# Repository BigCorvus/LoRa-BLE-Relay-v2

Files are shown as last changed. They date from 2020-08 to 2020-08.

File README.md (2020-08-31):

# LoRa-BLE-Relay-v2
second version of the nRF52840 and SX126x-based communication device intended to run Meshtastic-
This version is in the testing process. Not confirmed working yet.

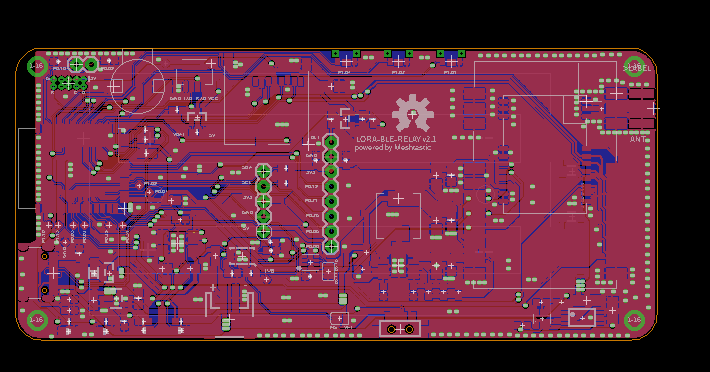
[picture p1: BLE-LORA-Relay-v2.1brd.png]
LoraRelayV2
  
See fourm discussion https://meshtastic.discourse.group/t/building-for-nrf52-boards/457/62  

The initial 2.0 version:  
LoraRelayV2  
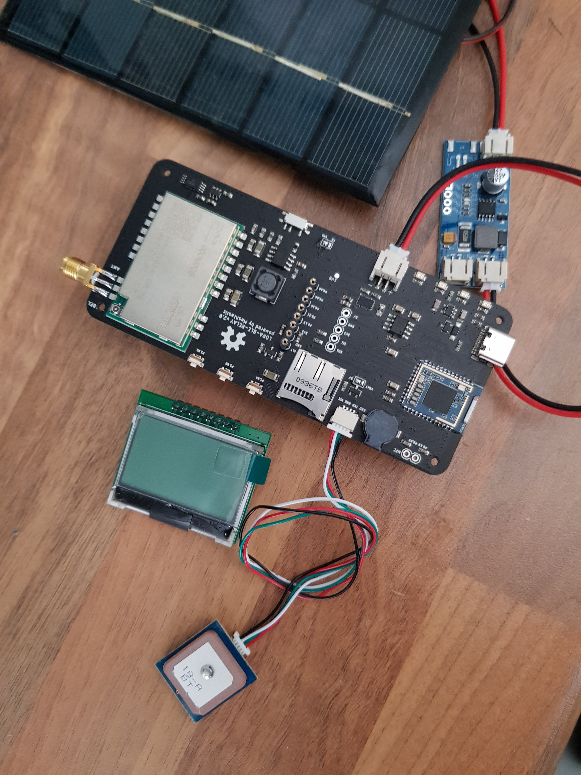
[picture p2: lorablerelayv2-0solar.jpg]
LoraRelayV2s
  

Features are: 
- 110x50mm  
- more ground plane for better LoRa RF performance
- low power consumption in receive mode and Bluetooth active: about 20mA for the 30dbm and 10mA for the 22dbm module version  
- nRF52840 module by Waveshare/HolyIOT with native USB bootloader, broken out NFC pins and good Arduino support (Adafruit Core)  
- Ebyte E22 LoRa Modules based on new Semtech SX126x chipsets for 22 or 30dbm and 915,868,433...Mhz frequency bands. 
- Footprint for both the big and the small LoRa module (the boost converter doesn't need to be assembled if the smaller one is used)  
- SD card slot (same card holder as in the Adafruit Adalogger boards  
- On board buzzer  
- GPS connector breaking out RXD and TXD (JST-SH 4-pin) with high-side power cutting option.   
- Many screen options: usual 128x64 OLEDs via I2C or sunlight-readable and power-efficient ST7565R and UC1701X LCD screens via bitbanged 4 line SPI (see BOM for variants)  
- display headers can be expansion headers  
- 3 nav buttons  
- powered from 1 or 2 parallel unprotected 18650 cells (protection circuitry on board)  
- port for external battery or solar charger for concurrent charging  
- battery temperature monitoring/environmental sensing via BME280  
- USB-C connector
- power management via TI fuel gauge IC with optional programmable power cutting option  (selectable via solder jumper, experimental!) 

To do in next version: reverse polarity protection for batteries.

Installation of the Arduino variant: put the variant.h and .cpp in a folder named LoRaBLERelayV2 which has to be created inside the variants folder of the nrf52 core. There you also have boards.txt which you have to extend by the content of the boards.txt inside this repo.

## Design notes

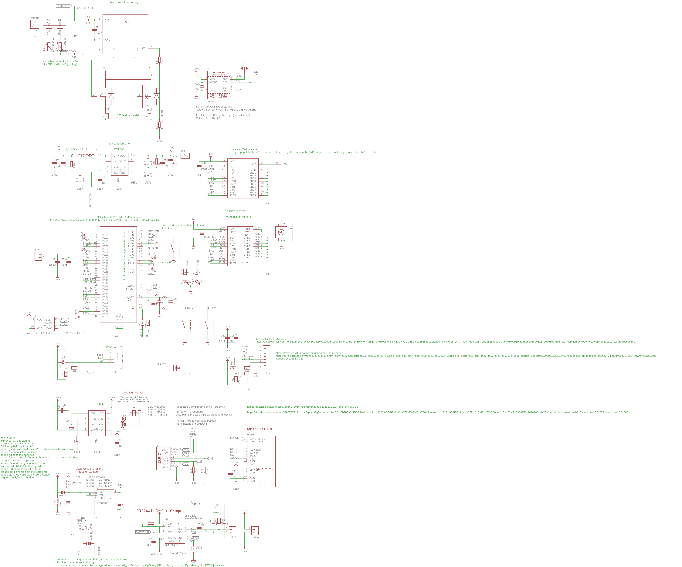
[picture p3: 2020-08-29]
BLE-LORA-Relay-v2.1.png

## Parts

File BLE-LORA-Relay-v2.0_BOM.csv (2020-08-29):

Qty | Value | Device | Package | Parts | Description | Search Keywords, remarks | Buying URL
3 |  | M02PTH | 1X02 | JP2, JP4, JP7 | Standard 2-pin 0.1 header. Use with"
1 |  | M08 | 1X08_ROUND | JP1 | Header 8
1 |  | PINHD-1X1 | 1X01 | JP3 | Pin header 1x1 for 0.1 spacing"
1 |  | SMACONNECTOR_EDGE | SMA_EDGELAUNCH | ANT | SMA Connector
1 |  | USB_C16PIN | USB-C-16P | J2 | USB Type C 16Pin Connector | USB Type c 16 pin | https://de.aliexpress.com/item/33056042016.html?spm=a2g0s.9042311.0.0.4a9b4c4dQIyuQ2
1 | 0.47uF | CAP0603-CAP | 0603-CAP | C4 | Capacitor
3 | 1.0uF | 1.0UF-16V-10%(0603) | 0603-CAP | C5, C12, C17 | CAP-00868
1 | 1.1k | R-EU_R0603 | R0603 | R4 | RESISTOR, European symbol
1 | 100R | R-EU_R0603 | R0603 | R23 | RESISTOR, European symbol
5 | 100k | R-EU_R0603 | R0603 | R25, R1, R2, R24, R28 | RESISTOR, European symbol
3 | 100n | 1.0UF-16V-10%(0603) | 0603-CAP | C11, C22, C3 | CAP-00868
4 | 100µ | C-EUC1206 | C1206 | C2, C16, C20, C21 | CAPACITOR, European symbol
2 | 10k | RESISTOR_0603_NOOUT | 0603-NO | R10, R11 | Resistors
1 | 10mOhm | R-EU_R0805 | R0805 | R5 | RESISTOR, European symbol
9 | 10...47uF | CAP_CERAMIC0805-NOOUTLINE | 0805-NO | C13, C15, C6, C7, C8, C10, C1, C9, C23 | Ceramic Capacitors
1 | 12k | R-EU_R0603 | R0603 | R20 | RESISTOR, European symbol
2 | 130pf | 1.0UF-16V-10%(0603) | 0603-CAP | C14, C19 | CAP-00868
7 | 1K | RESISTOR_0603_NOOUT | 0603-NO | R3, R7, R16, R17, R8, R26, R27 | Resistors
1 | 22R | RESISTOR_0603_NOOUT | 0603-NO | R22 | Resistors
1 | 27p | C-EUC0603 | C0603 | C18 | CAPACITOR, European symbol
1 | 2X18650 | 2X18650 | 2X18650 | U$10 |  | single or dual 18650 holder, surface mount | https://de.aliexpress.com/item/4000868337607.html?s=p&ad_pvid=20200719050327118341633435090009798010_2
1 | 3.3k | R-EU_R0603 | R0603 | R19 | RESISTOR, European symbol
1 | 4.7R | R-EU_R0603 | R0603 | R18 | RESISTOR, European symbol
4 | 5.1k | R-EU_R0603 | R0603 | R12, R13, R6, R9 | RESISTOR, European symbol
2 | 68R | RESISTOR_0603_NOOUT | 0603-NO | R14, R15 | Resistors
1 | 7.5MM-COIL | 7.5MM-COIL | 7.5MM_COIL | U$35
1 | 8205A | 8205A | TSSOP8 | U$46 | Dual Mosfet
1 | 82k | R-EU_R0603 | R0603 | R21 | RESISTOR, European symbol
1 | AP2112(3.3V) | VREG_SOT23-5 | SOT23-5 | U2 | SOT23-5 Fixed Voltage Regulators
1 | BLUE | LED0805_NOOUTLINE | CHIPLED_0805_NOOUTLINE | D4 | LED
1 | BME280 | BME280 | BME280 | U3 | BME280 - Environmental Sensor (I2C + SPI)
1 | BQ27441-G1 | BQ27441-G1 | PDSO-N12 | U1 | Fuel gauge IC
1 | BUZZER | BUZZER | BUZZER | U$2 |  | 9032 9,0 x 3.2 magnetic buzzer | https://de.aliexpress.com/item/4000148853278.html
3 | DMG2305 | MOSFET-P | SOT23-R | Q2, Q3, Q4 | P-Channel Mosfet
1 | DW-01 | DW-01 | SOT23-6 | U$38 | Lithium protection IC
1 | G5177C | G5177C | SO-08 | U$41 | Synchronous boost converter IC
1 | JST-SH-3 | JST-SH-3 | JST-SH-3 | U$17 | actually, surface mount 4-pin 1mm connector for GPS: JST-SH4
1 | JSTPH | CON_JST_PH_2PIN | JSTPH2 | X1 | JST 2-Pin Right-Angle Connector
3 | LS12T2 | LS12T2 | LS12T2 | DWN, DWN1, DWN2 | Pushbutton | Digikey 1642-1312-1-ND
1 | MBR120 | DIODE-SCHOTTKYSOD-123 | SOD-123 | D1
1 | NRF52840 | NRF52840 | NRF52840MOD | U$14 | Manufactued by HolyIOT or waveshare |  | https://de.aliexpress.com/item/32868002366.html?spm=a2g0s.9042311.0.0.27424c4duvmlGy
3 | RED | LED0805_NOOUTLINE | CHIPLED_0805_NOOUTLINE | D2, D3, D5 | LED
1 | SWITCH_SPDT | SWITCH_SPDT | KPS-1290 | U$45 | SWCH-10651 | SPDT MSK-12C02 | https://de.aliexpress.com/item/32856542440.html
1 | SX1262-30DBM | SX1262-30DBM | SX1262-30DBM | U$15 | 1W LoRa module by ebyte | search ebyte on aliexpress and get the E22 variants which can contain either a SX1262 or SX1268 and come in 22dbm or 30dbm variants
1 | SX1292-EBYTE | SX1292-EBYTE | SX1262_EBYTE | U$36 | 22dbm LoRa module by ebyte
1 | TP4056 | TP4056 | SO-08 | U$3 | Lithium charger
6 | TPSQTP13R | TPSQTP13R | TP13R | 1V8, 3V3, G, RST, SWC, SWD | Test pad
1 | microsd | MICROSD | MICROSD | X4 | MicroSD/Transflash Card Holder with SPI pinout |  | https://de.aliexpress.com/item/32607879172.html
1 | 1.4 inch ST7565 LCD 128x64 |  |  |  |  | preferred variant | https://de.aliexpress.com/item/32849604267.html
 | Alternative: UC1701X-based, bigger screen, same pinout, model: JLX12864G-086-P |  |  |  |  |  | https://de.aliexpress.com/item/32828243113.html
2 |  | Ferrite Bead 3A | 1206 | R29, 30 |  | 553-2402-1-ND Digikey

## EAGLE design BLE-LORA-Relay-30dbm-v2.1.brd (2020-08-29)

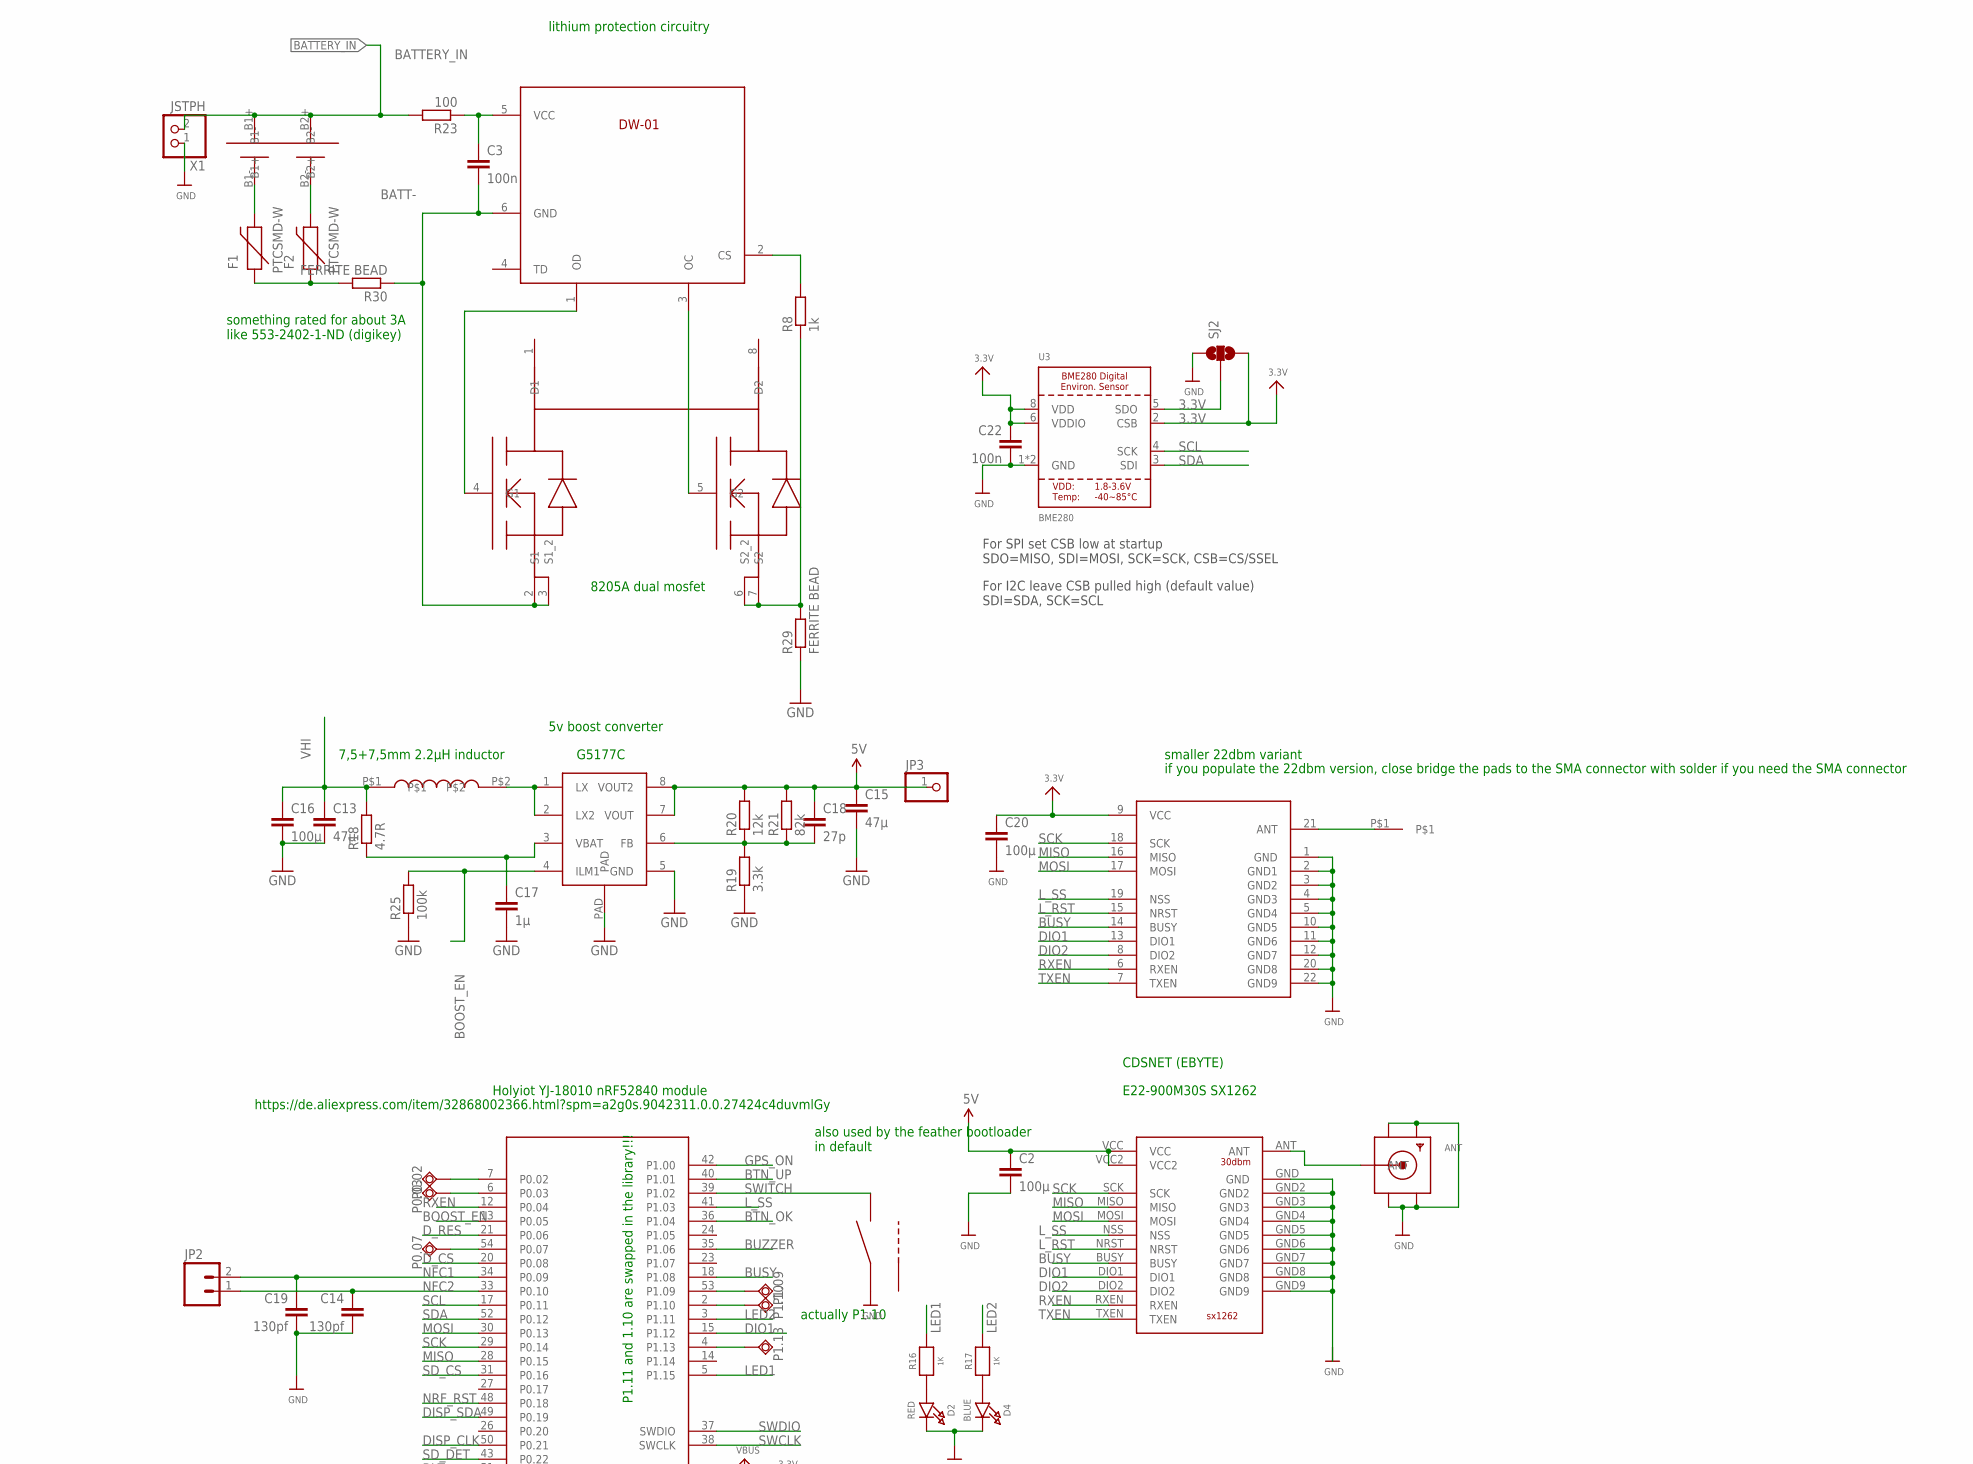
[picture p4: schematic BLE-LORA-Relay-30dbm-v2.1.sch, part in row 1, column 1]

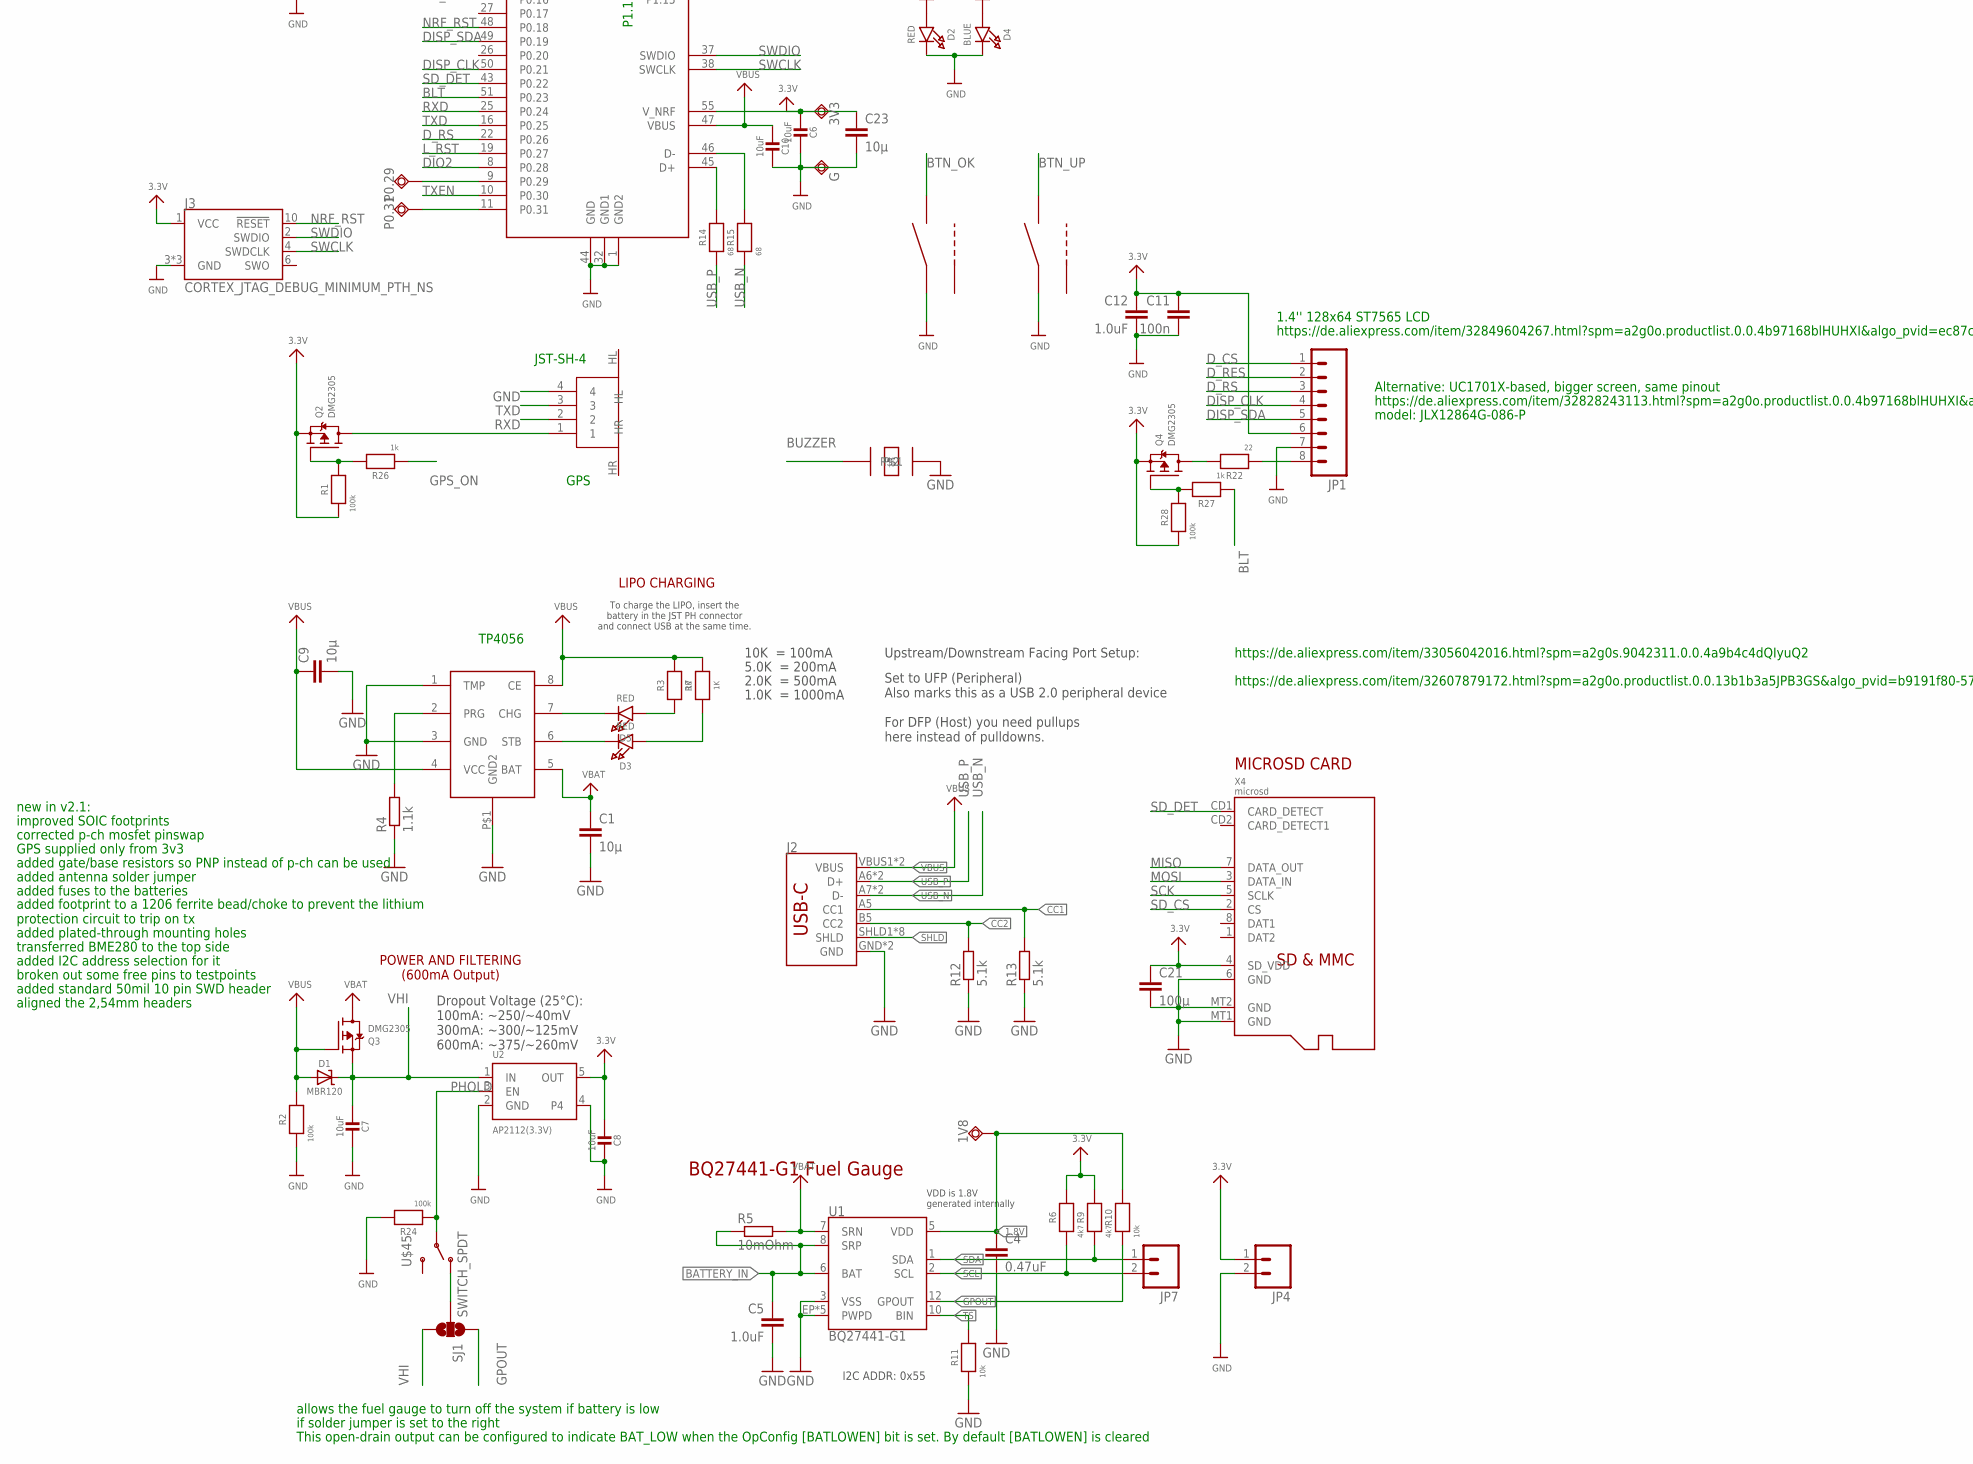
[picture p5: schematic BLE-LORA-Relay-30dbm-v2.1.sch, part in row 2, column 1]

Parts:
1V8, 3V3: TPSQTP13R; TP13R
ANT: SMACONNECTOR_EDGE; SMA_EDGELAUNCH
C1, C9, C23: 10µ; C0805
C2, C16, C20, C21: 100µ; C1206
C3: 100n; C0603
C4: 0.47uF; 0603-CAP
C5, C12: 1.0uF; 0603-CAP
C6, C7, C8, C10: 10uF; 0805-NO
C11, C22: 100n; 0603-CAP
C13, C15: 47µ; C0805
C14, C19: 130pf; 0603-CAP
C17: 1µ; C0603
C18: 27p; C0603
D1: MBR120; SOD-123
D2, D3, D5: RED; CHIPLED_0805_NOOUTLINE
D4: BLUE; CHIPLED_0805_NOOUTLINE
DWN, DWN1, DWN2: LS12T2
F1, F2: PTCSMD-W; PTC-1206-WIDE
G: TPSQTP13R; TP13R
J2: USB_C16PIN; USB-C-16P
J3: CORTEX_JTAG_DEBUG_MINIMUM_PTH_NS; 2X5-PTH-1.27MM-NO_SILK
JP1: M08; 1X08_ROUND
JP2, JP4, JP7: M02PTH; 1X02
JP3: PINHD-1X1; 1X01
P0.02, P0.03, P0.07, P0.29, P0.31, P1.09, P1.10, P1.13: TPSQTP13R; TP13R
Q2, Q3, Q4: DMG2305; SOT23-R
R1, R2, R24, R28: 100k; 0603-NO
R3, R7, R16, R17: 1K; 0603-NO
R4: 1.1k; R0603
R5: 10mOhm; R0805
R6, R9: 4k7; 0603-NO
R8: 1k; R0603
R10, R11: 10k; 0603-NO
R12, R13: 5.1k; R0603
R14, R15: 68; 0603-NO
R18: 4.7R; R0603
R19: 3.3k; R0603
R20: 12k; R0603
R21: 82k; R0603
R22: 22; 0603-NO
R23: 100; R0603
R25: 100k; R0603
R26, R27: 1k; 0603-NO
R29, R30: FERRITE BEAD; R1206
SJ1, SJ2: SOLDERJUMPER_2WAY-OLDS; SJ_3
U1: BQ27441-G1; PDSO-N12
U2: AP2112(3.3V); SOT23-5
U3: BME280
U$2: BUZZER
U$10: 2X18650
U$14: NRF52840; NRF52840MOD
U$15: SX1262-30DBM
U$17: JST-SH-3
U$35: 7.5MM-COIL; 7.5MM_COIL
U$36: SX1292-EBYTE; SX1262_EBYTE
U$38: DW-01; SOT23-6
U$39: G5177C_G5177C; G5177C_SO-08
U$41: SOLDERPAD
U$45: SWITCH_SPDT; KPS-1290
U$46: 8205A; TSSOP8
U$47: TP4056BETTER_TP4056; TP4056BETTER_SO-08
X1: JSTPH; JSTPH2
X4: microsd; MICROSD

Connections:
1.8V: 1V8.TP, C4.1, R10.2, U1.5 (VDD)
3.3V: 3V3.TP, C6.2, C8.2, C11.1, C12.1, C20.1, C21.1, C22.1, C23.1, J3.1 (VCC), JP1.6, JP4.1, Q2.2 (S), Q4.2 (S), R1.1, R6.2, R9.2, R28.1, SJ2.3, U2.5 (OUT), U3.2 (CSB), U3.6 (VDDIO), U3.8 (VDD), U$14.55 (V_NRF), U$36.9 (VCC), X4.4 (SD_VDD)
5V: C2.1, C15.1, C18.1, JP3.1, R20.2, R21.2, U$15.VCC, U$15.VCC2, U$39.7 (VOUT), U$39.8 (VOUT2)
ANT: ANT.P (ANT), U$15.ANT
BATT-: C3.2, R30.1, U$38.6 (GND), U$46.2 (S1), U$46.3 (S1_2)
BATTERY_IN: C5.1, R5.1, R23.2, U1.6 (BAT), U1.8 (SRP), U$10.B1+, U$10.B2+, X1.2
BLT: R27.1, U$14.51 (P0.23)
BOOST_EN: R25.2, U$14.13 (P0.05), U$39.4 (ILM1)
BTN_OK: DWN.1, U$14.36 (P1.04)
BTN_UP: DWN1.1, U$14.40 (P1.01)
BUSY: U$14.18 (P1.08), U$15.BUSY, U$36.14 (BUSY)
BUZZER: U$2.P$1, U$14.35 (P1.06)
CC1: J2.A5 (CC1), R13.2
CC2: J2.B5 (CC2), R12.2
DIO1: U$14.15 (P1.12), U$15.DIO1, U$36.13 (DIO1)
DIO2: U$14.8 (P0.28), U$15.DIO2, U$36.8 (DIO2)
DISP_CLK: JP1.4, U$14.50 (P0.21)
DISP_SDA: JP1.5, U$14.49 (P0.19)
D_CS: JP1.1, U$14.20 (P0.08)
D_RES: JP1.2, U$14.21 (P0.06)
D_RS: JP1.3, U$14.22 (P0.26)
FB: C18.2, R19.2, R20.1, R21.1, U$39.6 (FB)
GGGG: Q4.1 (G), R27.2, R28.2
GND: ANT.GND@1 (GND4), ANT.GND@2 (GND3), ANT.GND@3 (GND2), ANT.GND@4 (GND1), C1.2, C2.2, C4.2, C5.2, C6.1, C7.1, C8.1, C9.2, C10.1, C11.2, C12.2, C13.2, C14.2, C15.2, C16.2, C17.2, C19.2, C20.2, C21.2, C22.2, C23.2, D2.C, D4.C, DWN.2, DWN1.2, DWN2.2, G.TP, J2.GND, J2.GND2 (GND), J3.3 (GND), J3.5 (GND), J3.9 (GND), JP1.7, JP4.2, R2.1, R4.1, R11.1, R12.1, R13.1, R19.1, R24.2, R25.1, R29.1, SJ2.1, U1.3 (VSS), U1.EP (PWPD), U1.EP1 (PWPD), U1.EP2 (PWPD), U1.EP3 (PWPD), U1.EP4 (PWPD), U2.2 (GND), U2.4, U3.1 (GND), U3.7 (GND), U$2.P$2, U$14.1 (GND2), U$14.32 (GND1), U$14.44 (GND), U$15.GND, U$15.GND2, U$15.GND3, U$15.GND4, U$15.GND5, U$15.GND6, U$15.GND7, U$15.GND8, U$15.GND9, U$17.4, U$36.1 (GND), U$36.2 (GND1), U$36.3 (GND2), U$36.4 (GND3), U$36.5 (GND4), U$36.10 (GND5), U$36.11 (GND6), U$36.12 (GND7), U$36.20 (GND8), U$36.22 (GND9), U$39.5 (GND), U$39.PAD, U$47.1 (TMP), U$47.3 (GND), U$47.P$1 (GND2), X1.1, X4.6 (GND), X4.MT1 (GND), X4.MT2 (GND)
GPOUT: R10.1, SJ1.1, U1.12 (GPOUT)
GPS_ON: R26.1, U$14.42 (P1.00)
LED1: R16.2, U$14.5 (P1.15)
LED2: R17.2, U$14.3 (P1.11)
L_RST: U$14.19 (P0.27), U$15.NRST, U$36.15 (NRST)
L_SS: U$14.41 (P1.03), U$15.NSS, U$36.19 (NSS)
MISO: U$14.28 (P0.15), U$15.MISO, U$36.16 (MISO), X4.7 (DATA_OUT)
MOSI: U$14.30 (P0.13), U$15.MOSI, U$36.17 (MOSI), X4.3 (DATA_IN)
unnamed: D5.A, R3.1
unnamed: Q4.3 (D), R22.2
unnamed: SJ1.2, U$45.O
unnamed: JP1.8, R22.1
unnamed: Q2.1 (G), R1.2, R26.2
unnamed: R14.2, U$14.45 (D+)
unnamed: R15.2, U$14.46 (D-)
unnamed: D3.A, R7.1
unnamed: U$38.1 (OD), U$46.4 (G1)
unnamed: R4.2, U$47.2 (PRG)
unnamed: D3.C, U$47.6 (STB)
unnamed: D5.C, U$47.7 (CHG)
unnamed: D2.A, R16.1
unnamed: D4.A, R17.1
unnamed: Q2.3 (D), U$17.1
unnamed: C17.1, R18.1, U$39.3 (VBAT)
unnamed: U$35.P$2, U$39.1 (LX), U$39.2 (LX2)
unnamed: U$38.3 (OC), U$46.5 (G2)
unnamed: C3.1, R23.1, U$38.5 (VCC)
unnamed: U$36.21 (ANT), U$41.P$1
unnamed: F1.2, U$10.B1-
unnamed: F2.2, U$10.B2-
unnamed: R8.2, U$38.2 (CS)
unnamed: R8.1, R29.2, U$46.6 (S2_2), U$46.7 (S2)
unnamed: SJ2.2, U3.5 (SDO)
unnamed: P0.02.TP, U$14.7 (P0.02)
unnamed: P0.03.TP, U$14.6 (P0.03)
unnamed: P1.10.TP, U$14.2 (P1.10)
unnamed: P1.13.TP, U$14.4 (P1.13)
unnamed: P0.31.TP, U$14.11 (P0.31)
unnamed: P0.29.TP, U$14.9 (P0.29)
unnamed: P1.09.TP, U$14.53 (P1.09)
unnamed: P0.07.TP, U$14.54 (P0.07)
unnamed: F1.1, F2.1, R30.2
NFC1: C19.1, JP2.2, U$14.34 (P0.09)
NFC2: C14.1, JP2.1, U$14.33 (P0.10)
NRF_RST: J3.10 (!RESET), U$14.48 (P0.18)
PHOLD: R24.1, U2.3 (EN), U$45.P
RXD: U$14.25 (P0.24), U$17.2
RXEN: U$14.12 (P0.04), U$15.RXEN, U$36.6 (RXEN)
SCK: U$14.29 (P0.14), U$15.SCK, U$36.18 (SCK), X4.5 (SCLK)
SCL: JP7.2, R6.1, U1.2 (SCL), U3.4 (SCK), U$14.17 (P0.11)
SDA: JP7.1, R9.1, U1.1 (SDA), U3.3 (SDI), U$14.52 (P0.12)
SD_CS: U$14.31 (P0.16), X4.2 (CS)
SD_DET: U$14.43 (P0.22), X4.CD1 (CARD_DETECT)
SHLD: J2.SHLD1 (SHLD), J2.SHLD2 (SHLD), J2.SHLD3 (SHLD), J2.SHLD4 (SHLD), J2.SHLD5 (SHLD), J2.SHLD6 (SHLD), J2.SHLD7 (SHLD), J2.SHLD8 (SHLD)
SWCLK: J3.4 (SWDCLK), U$14.38 (SWCLK)
SWDIO: J3.2 (SWDIO), U$14.37 (SWDIO)
SWITCH: DWN2.1, U$14.39 (P1.02)
TS: R11.2, U1.10 (BIN)
TXD: U$14.16 (P0.25), U$17.3
TXEN: U$14.10 (P0.30), U$15.TXEN, U$36.7 (TXEN)
USB_N: J2.A7 (D-), J2.B7 (D-), R15.1
USB_P: J2.A6 (D+), J2.B6 (D+), R14.1
VBAT: C1.1, Q3.3 (D), R5.2, U1.7 (SRN), U$47.5 (BAT)
VBUS: C9.1, C10.2, D1.A, J2.VBUS1 (VBUS), J2.VBUS2 (VBUS), Q3.1 (G), R2.2, R3.2, R7.2, U$14.47 (VBUS), U$47.4 (VCC), U$47.8 (CE)
VHI: C7.2, C13.1, C16.1, D1.C, Q3.2 (S), R18.2, SJ1.3, U2.1 (IN), U$35.P$1

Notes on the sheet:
POWER AND FILTERING (600mA Output)
Dropout Voltage (25°C): 100mA: ~250/~40mV 300mA: ~300/~125mV 600mA: ~375/~260mV
10K = 100mA
5.0K = 200mA
2.0K = 500mA
1.0K = 1000mA
LIPO CHARGING
To charge the LIPO, insert the battery in the JST PH connector and connect USB at the same time.
BQ27441-G1 Fuel Gauge
VDD is 1.8V generated internally
I2C ADDR: 0x55
Holyiot YJ-18010 nRF52840 module
E22-900M30S SX1262
CDSNET (EBYTE)
7,5+7,5mm 2.2µH inductor
G5177C
P1.11 and 1.10 are swapped in the library!!!
GPS
allows the fuel gauge to turn off the system if battery is low
This open-drain output can be configured to indicate BAT_LOW when the OpConfig [BATLOWEN] bit is set. By default [BATLOWEN] is cleared
MICROSD CARD
Set to UFP (Peripheral) Also marks this as a USB 2.0 peripheral device For DFP (Host) you need pullups here instead of pulldowns.
Upstream/Downstream Facing Port Setup:
8205A dual mosfet
lithium protection circuitry
5v boost converter
JST-SH-4
TP4056
if solder jumper is set to the right
smaller 22dbm variant
also used by the feather bootloader in default
For SPI set CSB low at startup SDO=MISO, SDI=MOSI, SCK=SCK, CSB=CS/SSEL
For I2C leave CSB pulled high (default value) SDI=SDA, SCK=SCL
actually P1.10
https://de.aliexpress.com/item/33056042016.html?spm=a2g0s.9042311.0.0.4a9b4c4dQIyuQ2
https://de.aliexpress.com/item/32868002366.html?spm=a2g0s.9042311.0.0.27424c4duvmlGy
https://de.aliexpress.com/item/32607879172.html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,searchweb201602_,searchweb201603_
1.4'' 128x64 ST7565 LCD
https://de.aliexpress.com/item/32849604267.html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,searchweb201602_,searchweb201603_
https://de.aliexpress.com/item/32828243113.html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,searchweb201602_,searchweb201603_

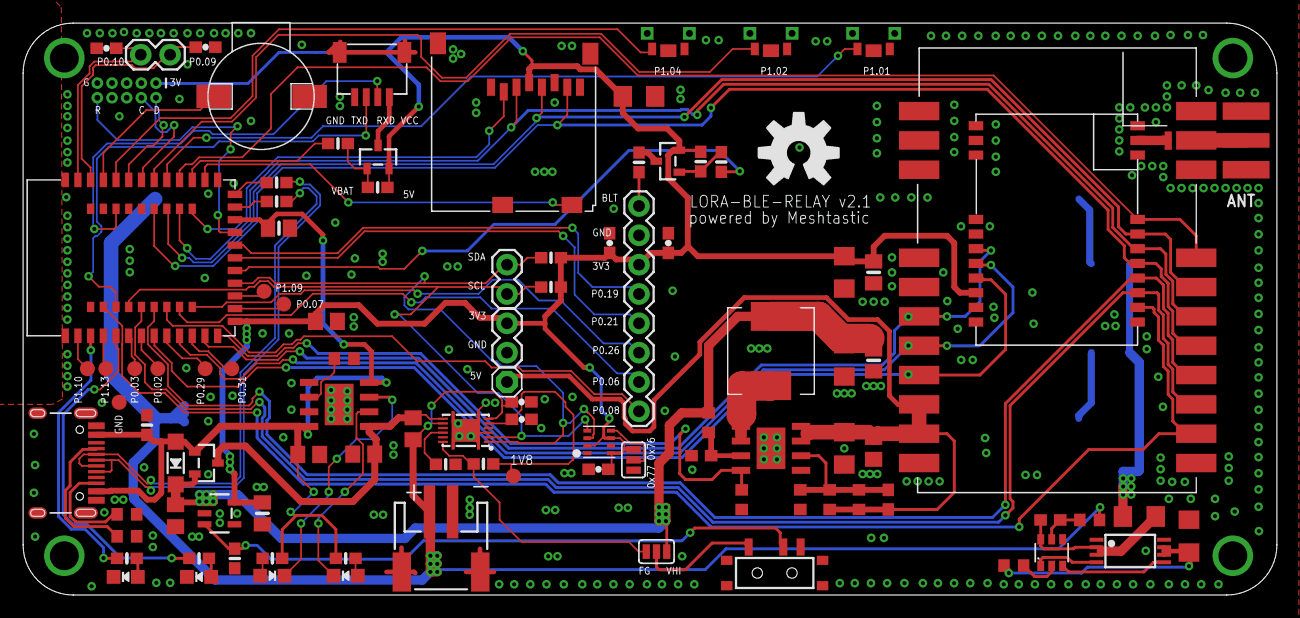
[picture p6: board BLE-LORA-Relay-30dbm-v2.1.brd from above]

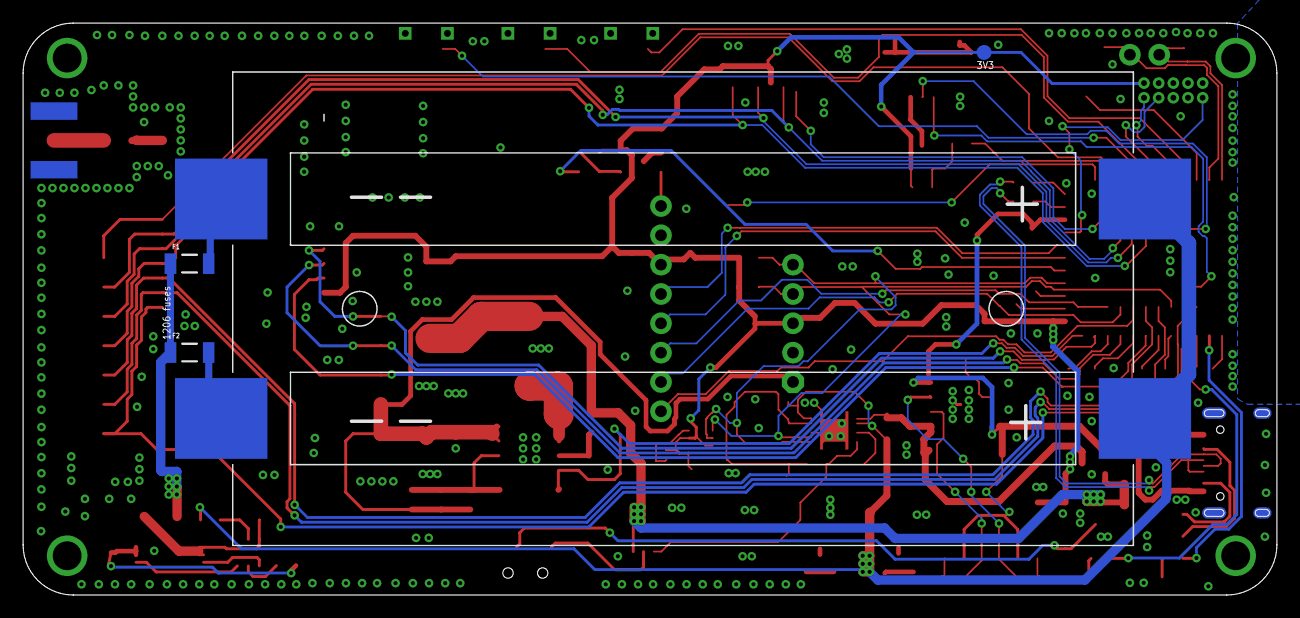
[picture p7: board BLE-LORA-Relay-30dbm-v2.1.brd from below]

Board: 2 copper layers, 108.6 x 49.5 mm, 106 parts (4 on the bottom side), 89 nets.

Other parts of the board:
U$7: OSHW-LOGO-L

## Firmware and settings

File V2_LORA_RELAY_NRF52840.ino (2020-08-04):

/*********************************************************************
  This is a basic firmware for for the LORA BLE relays
  Based on the BLE UART example by Adafruit.
  Tested on https://github.com/adafruit/Adafruit_nRF52_Arduino core 0.20.1
  Demontrates basic RX TX functionality by forwarding BLE data to LORA and vice versa, so the nRF UART app can be used to have a conversation via LORA.
  Also implements all the housekeeping such as the BQ27441 fuel gauge, ST7735 LCD and buttons.
  If using the Feather nrf52840 express bootloader the SWITCH button can be used to enter bootloader mode if pressed on startup. LED1 is the bootloader LED
  Note that you need to modify the variant.h and variant.cpp as described below in order to get software acces to certain pins. See the core documentation for more info on where to find those files.
  Also note that the PHOLD pin was separated from the rest of the circuit by cutting a trace on the PCB between the P0.05 pad on the nrf52840 module and the via next to it so the power latching circuit is not used.
  This will be corrected in an upcoming version of the design files.

*********************************************************************/
#include <bluefruit.h>
//#include <Adafruit_LittleFS.h>
//#include <InternalFileSystem.h>
#include <SPI.h>
#include <Wire.h>
#include <RadioLib.h>
#include <SparkFunBQ27441.h>

#include <Arduino.h>
#include <U8g2lib.h>

// Set BATTERY_CAPACITY to the design capacity of your battery.
const unsigned int BATTERY_CAPACITY = 3000; //


unsigned int soc = 0;


#define DIO1 (44)//P1.12
#define DIO2 (28)//P0.28
#define TXEN (30)//P0.30
#define RXEN (4)//P0.04
#define L_SS (35)//P1.03 
#define BUSY (40)//P1.08
#define L_RST (27)//P0.27

#define BTN_UP (33)//P1.01
#define BTN_DN (36)//P1.04 
#define SWITCH (34)//P1.02

#define LED2 (42)//P1.10
#define LED1 (47)//P1.15
#define PIEZO (38)//P1.06 

#define D_RES (6)//P0.06
#define D_CS (8)//P0.08
#define BLT (23)//P0.23
#define D_RS (26)//P0.26
#define DISP_SDA (19)//P0.19
#define DISP_CLK (21)//P0.21

#define SD_DET (22) //P0.22
#define SD_CS (16) //0.16

#define BOOST_EN (5) //P0.05
#define GPS_ON (32)//P1.00


// BLE Service
BLEDfu  bledfu;  // OTA DFU service
BLEDis  bledis;  // device information
BLEUart bleuart; // uart over ble
BLEBas  blebas;  // battery

// SX1262 has the following connections:
// NSS pin:
// DIO1 pin:
// NRST pin:  <--? actually DIO2
// BUSY pin:

SX1262 lora = new Module(L_SS, DIO1, -1, BUSY);

// flag to indicate that a packet was received
volatile bool receivedFlag = false;
unsigned long bltTimeout = 0;
boolean incomingMsg = false;

// disable interrupt when it's not needed
volatile bool enableInterrupt = true;

// For 1.44" and 1.8" TFT with ST7735 use
//Adafruit_ST7735 tft = Adafruit_ST7735(D_CS,  D_RS, D_RES);
// pin 9 - Serial data out (SID)
// pin 8 - Serial clock out (SCLK)
// pin 7 - Data/Command select (RS or A0)
// pin 6 - LCD reset (RST)
// pin 5 - LCD chip select (CS)
//ST7565 glcd(DISP_SDA, DISP_CLK, D_RS, D_RES, D_CS);
//https://github.com/olikraus/u8g2/issues/321
U8G2_ST7565_64128N_F_4W_SW_SPI u8g2(U8G2_R2, /* clock=*/DISP_CLK, /* data=*/ DISP_SDA, /* cs=*/ D_CS, /* dc=*/ D_RS, /* reset=*/D_RES);
//U8G2_UC1701_EA_DOGS102_F_4W_SW_SPI u8g2(U8G2_R2, /* clock=*/DISP_CLK, /* data=*/ DISP_SDA, /* cs=*/ D_CS, /* dc=*/ D_RS, /* reset=*/D_RES);

void setup()
{
  //WTF, Serial and the fuel gauge has to be initialized prior to the pins....
  //delay(1000);
  Serial.begin(115200);
  Serial1.begin(9600);
  delay(3000);

  setupBQ27441();
  soc = lipo.soc();  // Read state-of-charge (%)

  pinMode(LED1, OUTPUT);
  pinMode(LED2, OUTPUT);
  pinMode(BLT, OUTPUT); //LOW means ON
  pinMode(BOOST_EN, OUTPUT); //LOW means ON
  pinMode(GPS_ON, OUTPUT);
  pinMode(PIEZO, OUTPUT);

  pinMode(L_RST, OUTPUT);
  pinMode(TXEN, OUTPUT);
  pinMode(RXEN, OUTPUT);

  pinMode(BTN_UP, INPUT_PULLUP);
  pinMode(SWITCH, INPUT_PULLUP);
  pinMode(BTN_DN, INPUT_PULLUP);

  pinMode(SD_DET, INPUT);

  digitalWrite(BOOST_EN, HIGH);

  delay(1000);
  digitalWrite(BLT, LOW);
  pinMode(GPS_ON, LOW);
  delay(3000);
  digitalWrite(BLT, HIGH);
  pinMode(GPS_ON, HIGH);


  
  tone(PIEZO, 1000, 100);

  digitalWrite(L_RST, LOW);
  delay(100);
  digitalWrite(L_RST, HIGH);
  delay(100);
  prepareRX(); //switch RXEN and TXEN

  //Wire.begin();

  Serial.println("LORA BLE Relay based on nRF52840 and SX1262");
  Serial.println("---------------------------\n");

  Serial.print(F("[SX1262] Initializing ... "));
  // initialize SX1262
  // carrier frequency:           868.0 MHz
  // bandwidth:                   125.0 kHz
  // spreading factor:            7
  // coding rate:                 5
  // sync word:                   0x1424 (private network)
  // output power:                22 dBm
  // current limit:               60 mA
  // preamble length:             8 symbols
  // CRC:                         enabled
  //  int16_t begin(float freq = 434.0, float bw = 125.0, uint8_t sf = 9, uint8_t cr = 7, uint8_t syncWord = SX126X_SYNC_WORD_PRIVATE, int8_t power = 14, float currentLimit = 60.0, uint16_t preambleLength = 8, float tcxoVoltage = 1.6, bool useRegulatorLDO = false);
  int state = lora.begin(868.0, 125.0, 7, 5, 0x1424,18, 100, 8, 2.4, 0); //setting the output power too high can trip the lithium protection circuit :)

  if (state == ERR_NONE) {
    Serial.println(F("lora init success!"));
  } else {
    Serial.print(F("lora init failed, code "));
    Serial.println(state);
    //while (true);
  }

  // eByte E22-900M22S uses DIO3 to supply the external TCXO
  if (lora.setTCXO(2.4) == ERR_INVALID_TCXO_VOLTAGE)
  {
    Serial.println(F("Selected TCXO voltage is invalid for this module!"));
  }
  // set the function that will be called
  // when new packet is received
  lora.setDio1Action(setFlag);

  // start listening for LoRa packets
  Serial.print(F("[SX1262] Starting to listen ... "));
  state = lora.startReceive();
  if (state == ERR_NONE) {
    Serial.println(F("success!"));
  } else {
    Serial.print(F("failed, code "));
    Serial.println(state);
    while (true);
  }
  // if needed, 'listen' mode can be disabled by calling
  // any of the following methods:
  //
  // lora.standby()
  // lora.sleep()
  // lora.transmit();
  // lora.receive();
  // lora.readData();
  // lora.scanChannel();

  
  u8g2.begin();
  u8g2.clearBuffer();  // clear the internal memory
  u8g2.setFlipMode(1);
  u8g2.setFont(u8g2_font_ncenB08_tr); // choose a suitable font
  u8g2.setCursor(0, 10);
  u8g2.print("Batt:");// write something to the internal memory
  u8g2.setCursor(90, 10);
  u8g2.print(soc);// write something to the internal memory
  u8g2.print("%");
  u8g2.sendBuffer();          // transfer internal memory to the display

  // Setup the BLE LED to be enabled on CONNECT
  // Note: This is actually the default behaviour, but provided
  // here in case you want to control this LED manually via PIN 19
  //Bluefruit.autoConnLed(true);

  // Config the peripheral connection with maximum bandwidth
  // more SRAM required by SoftDevice
  // Note: All config***() function must be called before begin()
  Bluefruit.configPrphBandwidth(BANDWIDTH_MAX);

  Bluefruit.begin();
  Bluefruit.setTxPower(4);    // Check bluefruit.h for supported values
  Bluefruit.setName("LORA BLE Relay 30dbm");
  //Bluefruit.setName(getMcuUniqueID()); // useful testing with multiple central connections
  Bluefruit.Periph.setConnectCallback(connect_callback);
  Bluefruit.Periph.setDisconnectCallback(disconnect_callback);

  // To be consistent OTA DFU should be added first if it exists
  bledfu.begin();

  // Configure and Start Device Information Service
  bledis.setManufacturer("Adafruit Industries");
  bledis.setModel("Bluefruit Feather52");
  bledis.begin();

  // Configure and Start BLE Uart Service
  bleuart.begin();

  // Start BLE Battery Service
  blebas.begin();
  blebas.write(100);

  // Set up and start advertising
  startAdv();

  Serial.println("Please use Adafruit's Bluefruit LE app to connect in UART mode");
  Serial.println("Once connected, enter character(s) that you wish to send");
  // delay(2000);
  // digitalWrite(PHOLD,LOW);
  //digitalWrite(BLT, LOW);
  digitalWrite(LED2, LOW);

  attachInterrupt(BTN_UP, up_callback, ISR_DEFERRED | FALLING);
  attachInterrupt(SWITCH, sw_callback, ISR_DEFERRED | FALLING);
  attachInterrupt(BTN_DN, dn_callback, ISR_DEFERRED | FALLING);

  printBatteryStats();
}

void startAdv(void)
{
  // Advertising packet
  Bluefruit.Advertising.addFlags(BLE_GAP_ADV_FLAGS_LE_ONLY_GENERAL_DISC_MODE);
  Bluefruit.Advertising.addTxPower();

  // Include bleuart 128-bit uuid
  Bluefruit.Advertising.addService(bleuart);

  // Secondary Scan Response packet (optional)
  // Since there is no room for 'Name' in Advertising packet
  Bluefruit.ScanResponse.addName();

  /* Start Advertising
     - Enable auto advertising if disconnected
     - Interval:  fast mode = 20 ms, slow mode = 152.5 ms
     - Timeout for fast mode is 30 seconds
     - Start(timeout) with timeout = 0 will advertise forever (until connected)

     For recommended advertising interval
     https://developer.apple.com/library/content/qa/qa1931/_index.html
  */
  Bluefruit.Advertising.restartOnDisconnect(true);
  Bluefruit.Advertising.setInterval(32, 244);    // in unit of 0.625 ms
  Bluefruit.Advertising.setFastTimeout(30);      // number of seconds in fast mode
  Bluefruit.Advertising.start(0);                // 0 = Don't stop advertising after n seconds

  //printBatteryStats();
}


void setupBQ27441(void)
{
  // Use lipo.begin() to initialize the BQ27441-G1A and confirm that it's
  // connected and communicating.
  if (!lipo.begin()) // begin() will return true if communication is successful
  {
    // If communication fails, print an error message and loop forever.
    Serial.println("Error: Unable to communicate with BQ27441.");
    Serial.println("  Check wiring and try again.");
    Serial.println("  (Battery must be plugged into Battery Babysitter!)");
    //while (1) ;
  }
  Serial.println("Connected to BQ27441!");

  // Uset lipo.setCapacity(BATTERY_CAPACITY) to set the design capacity
  // of your battery.
  lipo.setCapacity(BATTERY_CAPACITY);
}

void printBatteryStats()
{
  // Read battery stats from the BQ27441-G1A
  unsigned int soc = lipo.soc();  // Read state-of-charge (%)
  unsigned int volts = lipo.voltage(); // Read battery voltage (mV)
  int current = lipo.current(AVG); // Read average current (mA)
  unsigned int fullCapacity = lipo.capacity(FULL); // Read full capacity (mAh)
  unsigned int capacity = lipo.capacity(REMAIN); // Read remaining capacity (mAh)
  int power = lipo.power(); // Read average power draw (mW)
  int health = lipo.soh(); // Read state-of-health (%)

  // Now print out those values:
  String toPrint = String(soc) + "% | ";
  toPrint += String(volts) + " mV | ";
  toPrint += String(current) + " mA | ";
  toPrint += String(capacity) + " / ";
  toPrint += String(fullCapacity) + " mAh | ";
  toPrint += String(power) + " mW | ";
  toPrint += String(health) + "%";

  Serial.println(toPrint);
}

void loop()
{
  //read gps serial
  if (Serial1.available()) {
    int inByte = Serial1.read();
    //Serial.write(inByte);
  }
  //printBatteryStats();
  //keep display backlight on for some seconds after incoming message
  if ((millis() - bltTimeout) > 5000 && incomingMsg == true) {
    digitalWrite(BLT, HIGH);
    incomingMsg = false;
  }

  // Forward data from HW Serial to BLEUART
  while (Serial.available())
  {
    // Delay to wait for enough input, since we have a limited transmission buffer
    delay(2);

    uint8_t buf[64];
    int count = Serial.readBytes(buf, sizeof(buf));
    bleuart.write( buf, count );
  }
  if (bleuart.available() > 0) {
    int BLEbytes = 0;
    uint8_t BLEbuf[64];
    // Forward from BLEUART to HW Serial
    while ( bleuart.available() )
    {
      uint8_t ch;
      ch = (uint8_t) bleuart.read();
      Serial.write(ch);
      BLEbuf[BLEbytes] = ch;
      BLEbytes++;
    }

    //now transmit via LORA
    prepareTX();
    Serial.print(F("[SX1262] Transmitting packet ... "));

    // you can transmit C-string or Arduino string up to
    // 256 characters long
    // NOTE: transmit() is a blocking method!
    //       See example SX126x_Transmit_Interrupt for details
    //       on non-blocking transmission method.
    //int state = lora.transmit("Hello World!");

    // you can also transmit byte array up to 256 bytes long
    int state = lora.transmit(BLEbuf, BLEbytes + 1);

    if (state == ERR_NONE) {
      // the packet was successfully transmitted
      Serial.println(F("success!"));

      // print measured data rate
      Serial.print(F("[SX1262] Datarate:\t"));
      Serial.print(lora.getDataRate());
      Serial.println(F(" bps"));
      delay(200);
      prepareRX();
    } else if (state == ERR_PACKET_TOO_LONG) {
      // the supplied packet was longer than 256 bytes
      Serial.println(F("too long!"));
    } else if (state == ERR_TX_TIMEOUT) {
      // timeout occured while transmitting packet
      Serial.println(F("timeout!"));
    } else {
      // some other error occurred
      Serial.print(F("failed, code "));
      Serial.println(state);
    }
  }
  // check if the flag is set
  if (receivedFlag) {
    // disable the interrupt service routine while
    // processing the data
    enableInterrupt = false;
    // reset flag
    receivedFlag = false;
    // you can read received data as an Arduino String
    String str;
    int state = lora.readData(str);
    // you can also read received data as byte array
    /*
      byte byteArr[8];
      int state = lora.readData(byteArr, 8);
    */
    if (state == ERR_NONE) {
      // packet was successfully received
      Serial.println(F("[SX1262] Received packet!"));

      // print data of the packet
      Serial.print(F("[SX1262] Data:\t\t"));
      Serial.println(str);
      bleuart.print(str); //send via BLE
      //tft.fillScreen(ST77XX_WHITE); //actually black
      digitalWrite(BLT, LOW);

      tone(PIEZO, 600, 200);
      delay(400);
      tone(PIEZO, 600, 200);
      u8g2.clearBuffer();
      u8g2.setCursor(0, 20);
      u8g2.print(str);
      unsigned int soc = lipo.soc();

      u8g2.setCursor(90, 10);
      u8g2.print(soc);
      u8g2.print("%");
      u8g2.setCursor(0, 50);
      u8g2.print("RSSI: ");
      u8g2.print(lora.getRSSI());
      u8g2.print("dBm ");
      u8g2.setCursor(0, 60);
      u8g2.print("SNR: ");
      u8g2.print(lora.getSNR());
      u8g2.print("dB");

      u8g2.sendBuffer();
      bltTimeout = millis();
      incomingMsg = true;

      // print RSSI (Received Signal Strength Indicator)
      Serial.print(F("[SX1262] RSSI:\t\t"));
      Serial.print(lora.getRSSI());
      Serial.println(F(" dBm"));
      // print SNR (Signal-to-Noise Ratio)
      Serial.print(F("[SX1262] SNR:\t\t"));
      Serial.print(lora.getSNR());
      Serial.println(F(" dB"));
    } else if (state == ERR_CRC_MISMATCH) {
      // packet was received, but is malformed
      Serial.println(F("CRC error!"));
    } else {
      // some other error occurred
      Serial.print(F("failed, code "));
      Serial.println(state);
    }
    // put module back to listen mode
    lora.startReceive();
    // we're ready to receive more packets,
    // enable interrupt service routine
    enableInterrupt = true;
  }

  delay(200); //remember: delay=sleep in the nrf52 RTOS-based core
}

//button callbacks
void up_callback(void)
{
  digitalWrite(BLT, LOW);
  unsigned int soc = lipo.soc();
  //tft.setCursor(135, 95);
  //tft.print(soc);
  //tft.println("%");

}

void sw_callback(void)
{
  digitalWrite(BLT, HIGH);
}


void dn_callback(void)
{
  prepareTX();
  Serial.print(F("[SX1262] Transmitting packet ... "));

  // you can transmit C-string or Arduino string up to
  // 256 characters long
  // NOTE: transmit() is a blocking method!
  //       See example SX126x_Transmit_Interrupt for details
  //       on non-blocking transmission method.
  int state = lora.transmit("Test");

  // you can also transmit byte array up to 256 bytes long
  /*
    byte byteArr[] = {0x01, 0x23, 0x45, 0x56, 0x78, 0xAB, 0xCD, 0xEF};
    int state = lora.transmit(byteArr, 8);
  */

  if (state == ERR_NONE) {
    // the packet was successfully transmitted
    Serial.println(F("success!"));

    // print measured data rate
    Serial.print(F("[SX1262] Datarate:\t"));
    Serial.print(lora.getDataRate());
    Serial.println(F(" bps"));
    delay(200);
    prepareRX();
  } else if (state == ERR_PACKET_TOO_LONG) {
    // the supplied packet was longer than 256 bytes
    Serial.println(F("too long!"));
  } else if (state == ERR_TX_TIMEOUT) {
    // timeout occured while transmitting packet
    Serial.println(F("timeout!"));
  } else {
    // some other error occurred
    Serial.print(F("failed, code "));
    Serial.println(state);

  }
}

void prepareTX(void) {

  digitalWrite(RXEN, LOW);
  digitalWrite(TXEN, HIGH);
}

void prepareRX(void) {
  digitalWrite(TXEN, LOW);
  digitalWrite(RXEN, HIGH);
}

// this function is called when a complete packet
// is received by the module
// IMPORTANT: this function MUST be 'void' type
//            and MUST NOT have any arguments!
void setFlag(void) {
  // check if the interrupt is enabled
  if (!enableInterrupt) {
    return;
  }
  // we got a packet, set the flag
  receivedFlag = true;
}

// callback invoked when central connects
void connect_callback(uint16_t conn_handle)
{
  // Get the reference to current connection
  BLEConnection* connection = Bluefruit.Connection(conn_handle);

  char central_name[32] = { 0 };
  connection->getPeerName(central_name, sizeof(central_name));
  digitalWrite(LED2, HIGH);
  //tft.setCursor(0, 95);
  //tft.print("BT");

  Serial.print("Connected to ");
  Serial.println(central_name);
}

/**
   Callback invoked when a connection is dropped
   @param conn_handle connection where this event happens
   @param reason is a BLE_HCI_STATUS_CODE which can be found in ble_hci.h
*/
void disconnect_callback(uint16_t conn_handle, uint8_t reason)
{
  (void) conn_handle;
  (void) reason;
  digitalWrite(LED2, LOW);
  //tft.setCursor(0, 95);
  //tft.print("  ");
  Serial.println();
  Serial.print("Disconnected, reason = 0x"); Serial.println(reason, HEX);
}

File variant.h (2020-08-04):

 /*
  Copyright (c) 2014-2015 Arduino LLC.  All right reserved.
  Copyright (c) 2016 Sandeep Mistry All right reserved.
  Copyright (c) 2018, Adafruit Industries (adafruit.com)

  This library is free software; you can redistribute it and/or
  modify it under the terms of the GNU Lesser General Public
  License as published by the Free Software Foundation; either
  version 2.1 of the License, or (at your option) any later version.
  This library is distributed in the hope that it will be useful,
  but WITHOUT ANY WARRANTY; without even the implied warranty of
  MERCHANTABILITY or FITNESS FOR A PARTICULAR PURPOSE.
  See the GNU Lesser General Public License for more details.
  You should have received a copy of the GNU Lesser General Public
  License along with this library; if not, write to the Free Software
  Foundation, Inc., 51 Franklin St, Fifth Floor, Boston, MA  02110-1301  USA
*/

#ifndef _VARIANT_LoRaBLERelayV2_
#define _VARIANT_LoRaBLERelayV2_

/** Master clock frequency */
#define VARIANT_MCK       (64000000ul)

#define USE_LFXO      // Board uses 32khz crystal for LF
// define USE_LFRC    // Board uses RC for LF

/*----------------------------------------------------------------------------
 *        Headers
 *----------------------------------------------------------------------------*/

#include "WVariant.h"

#ifdef __cplusplus
extern "C"
{
#endif // __cplusplus

// Number of pins defined in PinDescription array
#define PINS_COUNT           (48)
#define NUM_DIGITAL_PINS     (48)
#define NUM_ANALOG_INPUTS    (6) // A6 is used for battery, A7 is analog reference
#define NUM_ANALOG_OUTPUTS   (0)

// LEDs
#define PIN_LED1             (47)
#define PIN_LED2             (42)
//#define PIN_NEOPIXEL         (8)

#define LED_BUILTIN          PIN_LED1
#define LED_CONN             PIN_LED2

#define LED_RED              PIN_LED1
#define LED_BLUE             PIN_LED2

#define LED_STATE_ON         1         // State when LED is lit

/*
 * Buttons
 */
#define PIN_BUTTON1             (34)

/*
 * Analog pins
 */
#define PIN_A0               (3)
#define PIN_A1               (4)
#define PIN_A2               (28)
#define PIN_A3               (29)
#define PIN_A4               (30)
#define PIN_A5               (31)
#define PIN_A6               (0xff)
#define PIN_A7               (0xff)

static const uint8_t A0  = PIN_A0 ;
static const uint8_t A1  = PIN_A1 ;
static const uint8_t A2  = PIN_A2 ;
static const uint8_t A3  = PIN_A3 ;
static const uint8_t A4  = PIN_A4 ;
static const uint8_t A5  = PIN_A5 ;
static const uint8_t A6  = PIN_A6 ;
static const uint8_t A7  = PIN_A7 ;
#define ADC_RESOLUTION    14

// Other pins
#define PIN_AREF           31
//#define PIN_VBAT           PIN_A6
#define PIN_NFC1           (9)
#define PIN_NFC2           (10)

static const uint8_t AREF = PIN_AREF;

/*
 * Serial interfaces
 */
#define PIN_SERIAL1_RX       (24)
#define PIN_SERIAL1_TX       (25)

/*
 * SPI Interfaces
 */
#define SPI_INTERFACES_COUNT 1

#define PIN_SPI_MISO         (15)
#define PIN_SPI_MOSI         (13)
#define PIN_SPI_SCK          (14)

static const uint8_t SS   = (35);
static const uint8_t MOSI = PIN_SPI_MOSI ;
static const uint8_t MISO = PIN_SPI_MISO ;
static const uint8_t SCK  = PIN_SPI_SCK ;

/*
 * Wire Interfaces
 */
#define WIRE_INTERFACES_COUNT 1

#define PIN_WIRE_SDA         (12)
#define PIN_WIRE_SCL         (11)



// On-board QSPI Flash
//#define EXTERNAL_FLASH_DEVICES   GD25Q16C
//#define EXTERNAL_FLASH_USE_QSPI

#ifdef __cplusplus
}
#endif

/*----------------------------------------------------------------------------
 *        Arduino objects - C++ only
 *----------------------------------------------------------------------------*/

#endif

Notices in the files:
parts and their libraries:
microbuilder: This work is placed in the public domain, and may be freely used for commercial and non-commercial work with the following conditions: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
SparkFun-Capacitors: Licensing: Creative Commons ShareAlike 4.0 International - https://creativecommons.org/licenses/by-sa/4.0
